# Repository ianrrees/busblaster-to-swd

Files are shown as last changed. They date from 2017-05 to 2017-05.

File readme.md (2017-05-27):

JTAG adapter: 20-pin ARM to Cortex SWD w/ 10-pin 0.05" or 6-pin Tag Connect
===

Gerber files have been confirmed to work for basic SWD programming via the Tag Connect header.

Available from my DirtyPCBs shop: http://dirtypcbs.com/store/designer/details/9294/3545/busblaster-to-swd-gerbers-zip

The repo started out as a "universal adapter", which became somewhat intractable.
However, in that attempt I accumulated a few JTAG pinout links:

  * http://www.jtagtest.com/pinouts/ - Several pinouts
  * http://www.tincantools.com/assets/ARM20OnCE14_Rev-A_%20schematic.pdf - 20-pin TI
  * http://processors.wiki.ti.com/index.php/JTAG_Connectors - TI docs
  * http://www.analog.com/media/en/dsp-documentation/evaluation-kit-manuals/ICE_emu_1000_2000_rev_manual.pdf - Blackfin pinout
  * http://www.atmel.com/webdoc/atmelice/atmelice.using_ocd_physical_jtag.html - Atmel ICE
  * http://www.tag-connect.com/Materials/ARM20-CTX.pdf - Tag Connect's SWD adapter

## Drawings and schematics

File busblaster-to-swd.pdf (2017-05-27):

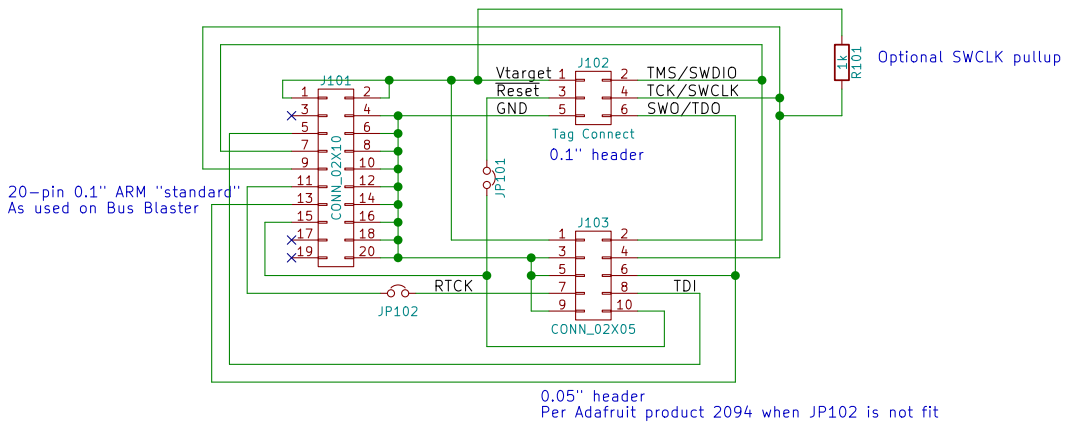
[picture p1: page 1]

Reset 3 | 4 | TCK/SWCLK
GND 5 | 6 SWO/TDO

9 | 10
11 | 12
13 | 14
15 | 16

J103 CONN_02X05 0.1" header 0.05" header Per Adafruit product 2094 when JP102 is not fit
TDI JP101

Id: 1/1 Title: File: busblaster-to-swd.sch Sheet: /

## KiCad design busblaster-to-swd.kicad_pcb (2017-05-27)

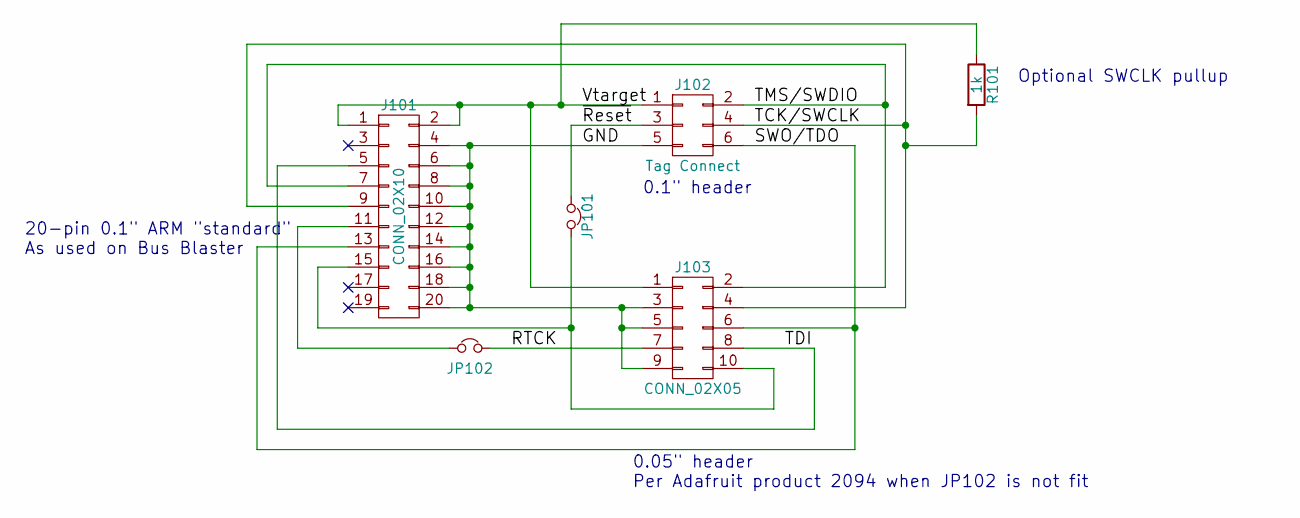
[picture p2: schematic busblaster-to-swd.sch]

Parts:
J101: CONN_02X10; Pin_Header_Straight_2x10_Pitch2.54mm
J102: Tag Connect; Pin_Header_Straight_2x03_Pitch2.54mm
J103: CONN_02X05; Pin_Header_Straight_2x05_Pitch1.27mm
JP101, JP102: Jumper_NC_Small; R_0603_HandSoldering
R101: 1k; R_0603_HandSoldering

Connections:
/GND: J101.4, J101.6, J101.8, J101.10, J101.12, J101.14, J101.16, J101.18, J101.20, J102.5, J103.3, J103.5, J103.9
/RTCK: J103.7, JP102.2
/SWO/TDO: J101.13, J102.6, J103.6
/TCK/SWCLK: J101.9, J102.4, J103.4, R101.2
/TDI: J101.5, J103.8
/TMS/SWDIO: J101.7, J102.2, J103.2
/Vtarget: J101.1, J101.2, J102.1, J103.1, R101.1
/~Reset: J102.3, JP101.1
unnamed: J101.11, JP102.1
unnamed: J101.15, J103.10, JP101.2

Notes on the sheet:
20-pin 0.1" ARM "standard" As used on Bus Blaster
0.1" header
0.05" header Per Adafruit product 2094 when JP102 is not fit
Optional SWCLK pullup

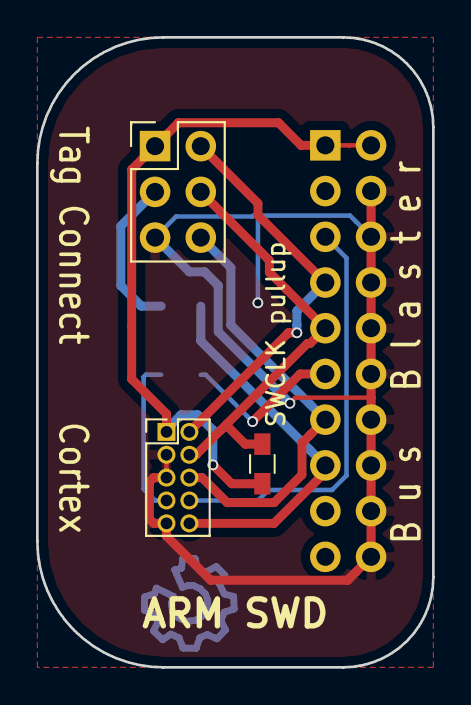
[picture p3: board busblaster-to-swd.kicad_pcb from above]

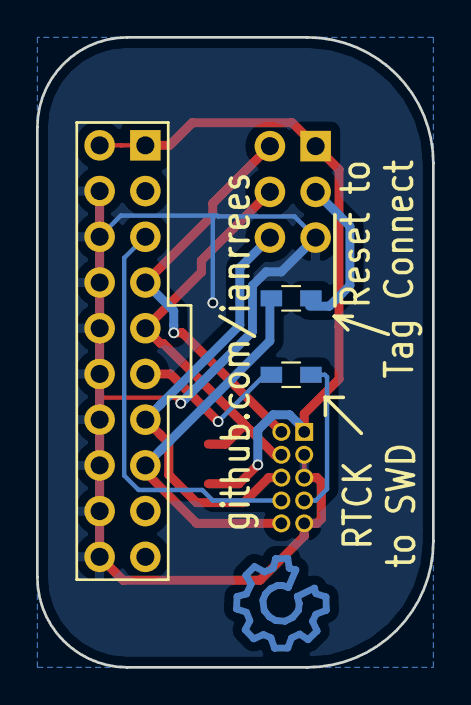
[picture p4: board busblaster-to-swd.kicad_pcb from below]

Board: 2 copper layers, 22.0 x 35.0 mm, 6 parts (2 on the bottom side), 10 nets.

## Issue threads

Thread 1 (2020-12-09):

SWCLK pullup footprint isn't accessible

ianrrees, 2020-12-09:

ianrrees, 2020-12-09:
Whoops, issue was observed with the first spin of these boards, the version in the repo already has this fixed...

Closed 2020-12-09.

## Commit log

2016-06-20 Initial commit.
    [bus blaster adapter.kicad_pcb, bus blaster adapter.sch]
2016-06-21 Changed half-done MSP430 to 10-pin Tag Connect
    [bus blaster adapter.sch]
2016-06-21 Added Blackfin
    [bus blaster adapter.sch]
2016-06-22 Tidy up, added VREF jumper to AVR.
    [bus blaster adapter.sch]
2016-06-26 Initial stab at a PCB layout
2016-07-18 Layout work, could probably use double checking...
    [bus blaster adapter.kicad_pcb, bus blaster adapter.sch]
2016-07-18 Copper pours!
    [bus blaster adapter.kicad_pcb]
2016-07-19 Tidy up, as much as one can call it that...
    [bus blaster adapter.kicad_pcb]
2017-04-16 Abort attempt at universal adapter
    [bus blaster adapter.kicad_pcb, bus blaster adapter.sch]
2017-04-16 Quick schematic + layout
    [busblaster-to-swd.kicad_pcb, busblaster-to-swd.sch]
2017-04-16 Update 20-pin TI link
2017-04-30 Add SWCLK pullup resistor footprint
    [busblaster-to-swd.kicad_pcb, busblaster-to-swd.sch]
2017-05-03 Updated layout and included gerbers as ordered
    [busblaster-to-swd.kicad_pcb]
2017-05-27 Connect SWO to Tag-Connect, move SWCLK pullup
    [busblaster-to-swd.kicad_pcb, busblaster-to-swd.sch]
2017-05-27 Add pdf of schematic
